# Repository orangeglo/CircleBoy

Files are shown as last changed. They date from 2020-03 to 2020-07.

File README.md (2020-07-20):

# CircleBoy
CirlceBoy is a small circuit board that lets you replace the directional pad on a gameboy or other device with an analog joystick. CircleBoy was designed specifically to use the 3DS circle pad with a gameboy, but is adaptable to tons of use cases.

## Installation Gallery
A gallery of my installation of the board can be [found here](https://imgur.com/a/vMOLDO8).

## Configuration
You can select between 4 different modes for the stick. Modes are selected by shorting out the dpad contacts in the appropriate direction when you turn the system on. The configuration is stored in the EEPROM of the chip, so you only have to set it once.

Direction | Deadzone | Segments
--- | --- | ---
Up (default) | Small | Balanced
Down          | Large | Balanced
Left          | Small | 3/4 Straight, 1/4 Diagonals
Right         | Large | 3/4 Straight, 1/4 Diagonals

## ATtiny85 Fuses
Since this project uses the reset line on the ATtiny85, once you've written the firmware and enabled the `NO_GOING_BACK_NOW` macro, you'll need to disable the reset on the chip. I did this on my Mac with
```
/Applications/Arduino.app/Contents/Java/hardware/tools/avr/bin/avrdude -C/Applications/Arduino.app/Contents/Java/hardware/tools/avr/etc/avrdude.conf -v -v -v -v -pattiny85 -carduino -P/dev/cu.usbmodem143301 -b19200 -Uhfuse:w:0x5f:m
```
The important part of that is setting the hfuse to 0x5f.

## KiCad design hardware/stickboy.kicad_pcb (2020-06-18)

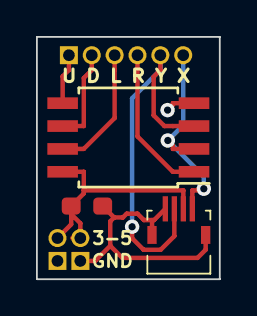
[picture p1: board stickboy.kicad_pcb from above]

Board: 2 copper layers, 10.2 x 13.5 mm, 6 parts (0 on the bottom side), 8 nets.

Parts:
C1: 0.1 uF; C_0603_1608Metric_Pad1.05x0.95mm_HandSolder
J1, J4: power; PinHeader_1x02_P1.27mm_Vertical
J2: pins; PinHeader_1x06_P1.27mm_Vertical
J3: 59453-041110EDHLF; 59453041110EDHLF
U1: ATtiny85-20SU; SOIJ-8_5.3x5.3mm_P1.27mm

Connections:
GND: C1.2, J1.1, J3.1, J3.MP1, J3.MP2, J4.1, U1.4
unnamed: J2.1, U1.5
unnamed: J2.2, U1.6
unnamed: J2.3, U1.7
unnamed: J2.4, U1.1
unnamed: J2.5, J3.2, U1.3
unnamed: J2.6, J3.4, U1.2
VCC: C1.1, J1.2, J3.3, J4.2, U1.8

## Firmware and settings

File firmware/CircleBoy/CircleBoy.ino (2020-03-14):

#include <EEPROM.h>

#define X_PIN A3
#define Y_PIN A2
#define UP_PIN 0
#define DOWN_PIN 1
#define LEFT_PIN 2
#define RIGHT_PIN 5 // reset

#define CHECKSUM_ADDRESS 0x01
#define CHECKSUM_VALUE 0x69
#define CONFIG_ADDRESS 0x00
#define CONFIG_WAIT_TIME 500

#define UP_CONFIG 0
#define DOWN_CONFIG 1
#define LEFT_CONFIG 2
#define RIGHT_CONFIG 3

#define NO_GOING_BACK_NOW false // flipping to true will disable programming by using the reset line (enables right)

byte currentConfig = UP_CONFIG;
const int centerX = 515;
const int centerY = 512;
int x, y, mag;
float ang;
bool upPressed, downPressed, leftPressed, rightPressed = false;

void setup() {
  readConfig();
  checkForNewConfig();
  writeConfig();
}

void loop() {
  clearPresses();
  
  x = analogRead(X_PIN);
  y = analogRead(Y_PIN);
  mag = magnitude(x, y);
  ang = angle(x, y);
  if (ang < 0) { ang += 6.2832; }

  switch(currentConfig) {
    case DOWN_CONFIG:
      setStickEvenSegments(200);
      break;
    case LEFT_CONFIG:
      setStickUnevenSegments(150);
      break;
    case RIGHT_CONFIG:
      setStickUnevenSegments(200);
      break;
    default: // UP_CONFIG
      setStickEvenSegments(150);
  }

  writePresses();

  delay(1);
}

void clearPresses() {
  upPressed = false;
  downPressed = false;
  leftPressed = false;
  rightPressed = false;
}

void writePresses(){
  if (upPressed) { pinMode(UP_PIN, OUTPUT); digitalWrite(UP_PIN, LOW); }
  else { pinMode(UP_PIN, INPUT); }

  if (downPressed) { pinMode(DOWN_PIN, OUTPUT); digitalWrite(DOWN_PIN, LOW); }
  else { pinMode(DOWN_PIN, INPUT); }

  if (leftPressed) { pinMode(LEFT_PIN, OUTPUT); digitalWrite(LEFT_PIN, LOW); }
  else { pinMode(LEFT_PIN, INPUT); }

  if (NO_GOING_BACK_NOW) {
    if (rightPressed) { pinMode(RIGHT_PIN, OUTPUT); digitalWrite(RIGHT_PIN, LOW); }
    else { pinMode(RIGHT_PIN, INPUT); }
  }
}

int magnitude(int x, int y) {
  return sqrt((pow(x - centerX, 2) + pow(y - centerY, 2)));
}

double angle(int x, int y){
  return atan2(y - centerY, x - centerX);
}

byte checksum;
void readConfig() {
  EEPROM.get(CHECKSUM_ADDRESS, checksum);
  if (checksum == CHECKSUM_VALUE){
    EEPROM.get(CONFIG_ADDRESS, currentConfig);
  } else {
    EEPROM.write(CHECKSUM_ADDRESS, CHECKSUM_VALUE);
    EEPROM.write(CONFIG_ADDRESS, currentConfig);
  }
}

void writeConfig() {
  EEPROM.update(CONFIG_ADDRESS, currentConfig);
}

int configStartTime;
void checkForNewConfig(){
  configStartTime = millis();
  while (millis() - configStartTime < CONFIG_WAIT_TIME) {
    if (!digitalRead(UP_PIN)) { currentConfig = UP_CONFIG; }
    else if (!digitalRead(DOWN_PIN)) { currentConfig = DOWN_CONFIG; }
    else if (!digitalRead(LEFT_PIN)) { currentConfig = LEFT_CONFIG; }
    else if (!digitalRead(RIGHT_PIN)) { currentConfig = RIGHT_CONFIG; }
  }
}

void setStickEvenSegments(int threshold) {
  if (mag > threshold) {
    if (ang >= 0.3972 && ang <= 1.1781){ upPressed = true; rightPressed = true; } // up right
    else if (ang >= 1.1781 && ang <= 1.9635){ upPressed = true; } // up
    else if (ang >= 1.9635 && ang <= 2.7489){ upPressed = true; leftPressed = true; } // up left
    else if (ang >= 2.7489 && ang <= 3.5343){ leftPressed = true; } // left
    else if (ang >= 3.5343 && ang <= 4.3197){ downPressed = true; leftPressed = true; } // down left
    else if (ang >= 4.3197 && ang <= 5.1051){ downPressed = true; } // down
    else if (ang >= 5.1051 && ang <= 5.8905){ downPressed = true; rightPressed = true; } // down right
    else if (ang >= 5.8905 || ang <= 0.3972){ rightPressed = true; } // right
  }
}

void setStickUnevenSegments(int threshold) { // 1/4 diagonals, 3/4 straights
  if (mag > threshold) {
    if (ang >= 0.58904 && ang <= 0.98174){ upPressed = true; rightPressed = true; } // up right
    else if (ang >= 0.98174 && ang <= 2.15984){ upPressed = true; } // up
    else if (ang >= 2.15984 && ang <= 2.55254){ upPressed = true; leftPressed = true; } // up left
    else if (ang >= 2.55254 && ang <= 3.73063){ leftPressed = true; } // left
    else if (ang >= 3.73063 && ang <= 4.12333){ downPressed = true; leftPressed = true; } // down left
    else if (ang >= 4.12333 && ang <= 5.30143){ downPressed = true; } // down
    else if (ang >= 5.30143 && ang <= 5.69413){ downPressed = true; rightPressed = true; } // down right
    else if (ang >= 5.69413 || ang <= 0.58904){ rightPressed = true; } // right
  }
}
